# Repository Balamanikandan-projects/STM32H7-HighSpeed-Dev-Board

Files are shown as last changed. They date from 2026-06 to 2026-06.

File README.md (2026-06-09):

# STM32H7-HighSpeed-Dev-Board
An interview-ready, high-performance development platform designed around the ARM Cortex-M7 **STM32H743VIT6** microcontroller (operating at up to 480 MHz). This project showcases advanced hardware engineering principles, including 4-layer PCB stackup optimization, high-speed digital signal integrity, and isolated power management switching nodes.

## 🚀 Key Features & Specifications
* **Core Processor:** STM32H743VIT6 (ARM Cortex-M7, 480 MHz, 100-pin LQFP package).
* **Power Management:** On-board **TLV62569** high-efficiency synchronous DC-DC buck regulator stepping down 5V USB power to a stable 3.3V system rail.
* **Storage Interface:** MicroSD Card slot supporting high-bandwidth SDMMC communication profiles.
* **Connectivity:** Integrated USB-C interface protected by a **USBLC6-2SC6** low-capacitance ESD protection array.
* **Clock Systems:** Dual external oscillators—a high-speed 25 MHz system clock and a low-speed 32.768 kHz RTC clock with optimized parallel trace routing.

---

## 🛠️ Hardware Architecture & Schematic Layout

The schematic is organized into strict, modular functional blocks to ensure clean system readability:
1. **Power Supply & Input:** Raw 5V input via USB-C routed directly through ESD clamping protection into the synchronous buck regulator loop.
2. **Core Processor:** Centralized STM32H7 MCU hub surrounded closely by dedicated decoupling capacitor networks.
3. **Peripheral Storage:** High-speed data links mapped to the MicroSD interface.








---

## 🏎️ PCB Design & Signal Integrity (SI) Strategy

Designing for a 480 MHz processor requires moving beyond standard 2-layer routing limitations. This board utilizes a professional **4-layer stackup** optimized for electromagnetic compatibility (EMC):

### 🥞 4-Layer Stackup Assignment
* **Layer 1 (Top):** Component placement and high-speed signal routing.
* **Layer 2 (Inner 1):** Solid, unbroken **GND Reference Plane**.
* **Layer 3 (Inner 2):** Power Plane split into 5V and 3.3V distribution zones.
* **Layer 4 (Bottom):** Slower control lines and trace cleanup.

### 📐 Engineering Layout Constraints Implemented
* **Minimized Return Path Loops:** Every single ground pad drops directly into the Layer 2 GND plane using an adjacent via, dropping loop inductance to near-zero and eliminating ground bounce.
* **High-Speed Clock Routing:** The 25 MHz oscillator lines are short, perfectly symmetric, and run completely parallel to eliminate phase jitter.
* **EMI Suppression:** The switching node of the TLV62569 buck regulator (including input/output caps and the 1.5µH inductor) is laid out in a tight, isolated geometric loop to compress high-frequency switching noise away from analog rails.




---

## 📦 Manufacturing & Assembly Ready

The project contains a complete, automated manufacturing release package generated directly from KiCad:
* **Gerber Blueprints:** Complete 4-layer physical production layers.
* **Excellon Drill Files:** Accurate CNC hole dimensions for vias and mounting pins.
* **Bill of Materials (BOM):** Fully specified manufacturing part numbers.
* **Component Placement Files (CPL):** Pick-and-place centroid data ($X,Y$ coordinates and rotation angles) for automated assembly.

### 🔍 3D Board Visualization




---

## 📂 How to Open This Project
1. Clone this repository.
2. Download and install **KiCad v7 or later**.
3. Open the `.kicad_pro` project file to explore the fully cleared DRC schema and layout!

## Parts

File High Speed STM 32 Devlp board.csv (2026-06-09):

Id | Designator | Footprint | Quantity | Designation | Supplier and ref
1 | C_out_2,C_out_1 | C_0603_1608Metric | 2 | 22uF
2 | C11,C12,C6,C10,C7,C13,C9,C5 | C_0603_1608Metric | 8 | 100nF
3 | SW1 | SW_MEC_5GSH9 | 1 | SW_MEC_5G
4 | C3,C4 | C_0603_1608Metric | 2 | 10pF
5 | Y1 | Crystal_SMD_3215-2Pin_3.2x1.5mm | 1 | 32.768kHz
6 | C17,C16 | C_0603_1608Metric | 2 | 2.2uF
7 | 25MHz1 | Crystal_SMD_3225-4Pin_3.2x2.5mm | 1 | Crystal_GND23
8 | FB1 | R_0603_1608Metric | 1 | FerriteBead
9 | R_Damp1 | R_0603_1608Metric | 1 | 22ohm
10 | C18 | C_0603_1608Metric | 1 | 10nF
11 | J2 | PinHeader_1x05_P2.54mm_Vertical | 1 | Conn_01x05_Pin
12 | C2,C1 | C_0603_1608Metric | 2 | 12pF
13 | R2,R1 | R_0603_1608Metric | 2 | 5.1K
14 | L1 | L_Wuerth_MAPI-3012 | 1 | 1.5uH
15 | C_in1,C8 | C_0603_1608Metric | 2 | 10uF
16 | U1 | SOT-23-6 | 1 | USBLC6-2SC6
17 | C15 | C_0603_1608Metric | 1 | 4.7uf
18 | U2 | SOT-23-5 | 1 | TLV62569DBVR
19 | J3 | microSD_HC_Molex_47219-2001 | 1 | Micro_SD_Card
20 | R3 | R_0603_1608Metric | 1 | 10K
21 | C14 | C_0603_1608Metric | 1 | 4.7uF
22 | U3 | LQFP-100-1EP_14x14mm_P0.5mm_EP6.9x6.9mm | 1 | STM32H743VIT6TR
23 | J1 | USB_C_Receptacle_GCT_USB4085 | 1 | USB_C_Receptacle_USB2.0_16P

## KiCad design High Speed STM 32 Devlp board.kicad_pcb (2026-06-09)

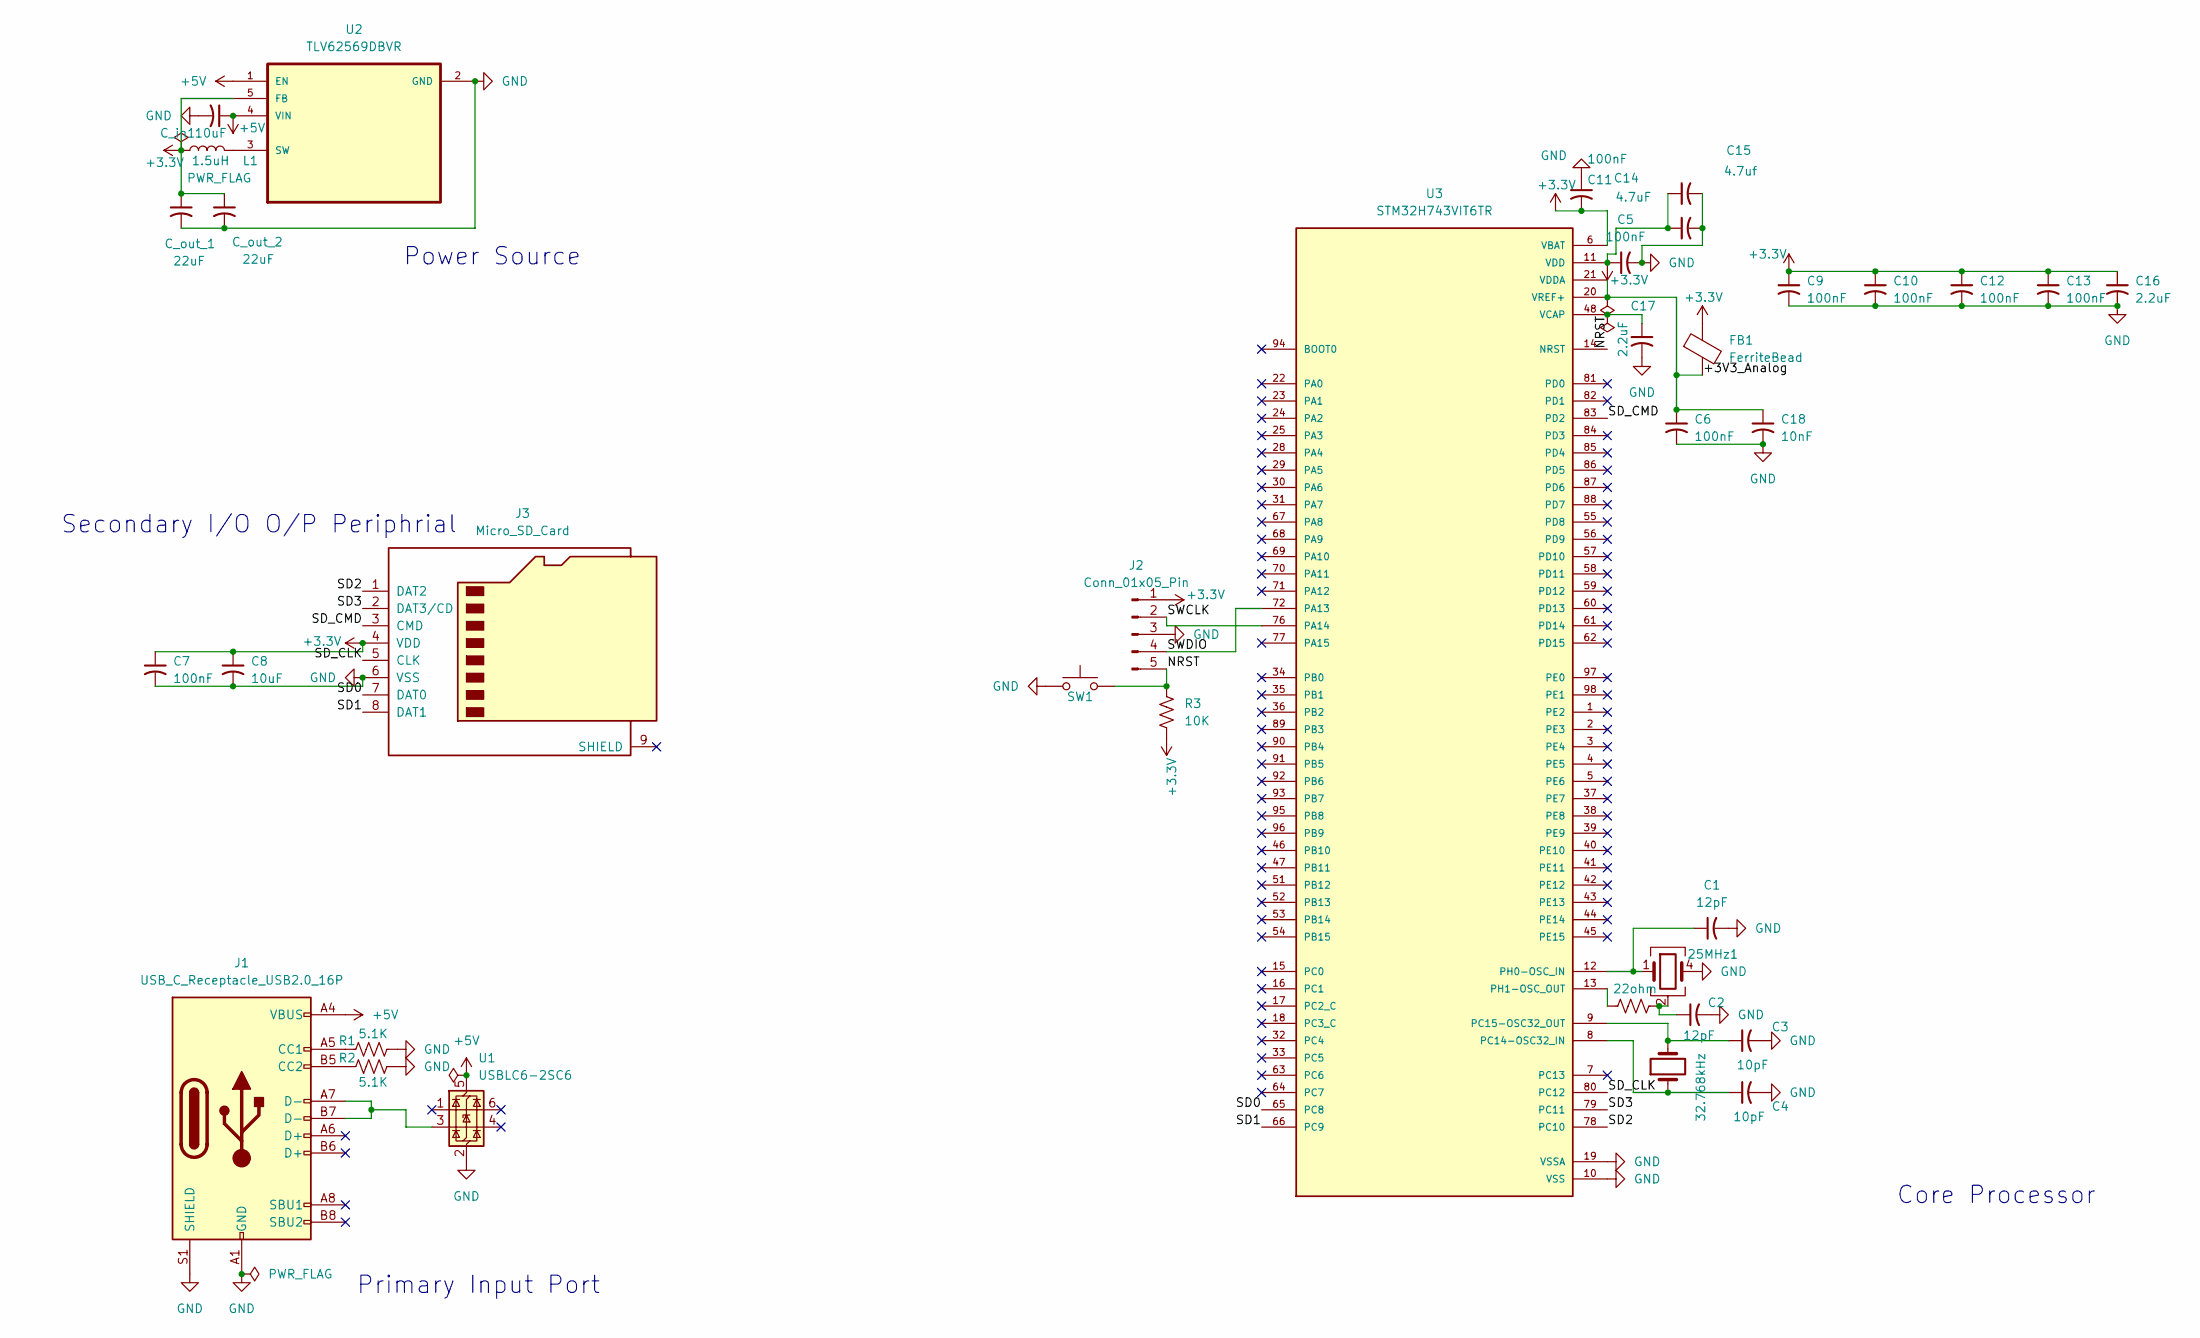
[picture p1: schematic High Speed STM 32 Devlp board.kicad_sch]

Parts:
25MHz1: Crystal_GND23; Crystal_SMD_3225-4Pin_3.2x2.5mm
C1, C2: 12pF; C_0603_1608Metric
C3, C4: 10pF; C_0603_1608Metric
C5, C6, C7, C9, C10, C11, C12, C13: 100nF; C_0603_1608Metric
C8: 10uF; C_0603_1608Metric
C14: 4.7uF; C_0603_1608Metric
C15: 4.7uf; C_0603_1608Metric
C16, C17: 2.2uF; C_0603_1608Metric
C18: 10nF; C_0603_1608Metric
C_in1: 10uF; C_0603_1608Metric
C_out_1, C_out_2: 22uF; C_0603_1608Metric
FB1: FerriteBead; R_0603_1608Metric
J1: USB_C_Receptacle_USB2.0_16P; USB_C_Receptacle_GCT_USB4085
J2: Conn_01x05_Pin; PinHeader_1x05_P2.54mm_Vertical
J3: Micro_SD_Card; microSD_HC_Molex_47219-2001
L1: 1.5uH; L_Wuerth_MAPI-3012
R1, R2: 5.1K; R_0603_1608Metric
R3: 10K; R_0603_1608Metric
R_Damp1: 22ohm; R_0603_1608Metric
SW1: SW_MEC_5G; SW_MEC_5GSH9
U1: USBLC6-2SC6; SOT-23-6
U2: TLV62569DBVR; SOT-23-5; DigiKey_Part_Number 296-47360-1-ND
U3: STM32H743VIT6TR; LQFP-100-1EP_14x14mm_P0.5mm_EP6.9x6.9mm; PARTREV 7; DigiKey_Part_Number 497-STM32H743VIT6TRCT-ND
Y1: 32.768kHz; Crystal_SMD_3215-2Pin_3.2x1.5mm

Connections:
+3.3V: C5.1, C7.1, C8.1, C9.1, C10.1, C11.2, C12.1, C13.1, C14.1, C15.1, C16.1, C_out_1.1, C_out_2.1, FB1.1, J2.1, J3.4 (VDD), L1.1, R3.1, U2.5 (FB), U3.6 (VBAT), U3.11 (VDD), U3.27 (VDD), U3.50 (VDD), U3.75 (VDD), U3.100 (VDD)
+5V: C_in1.1, J1.A4 (VBUS), J1.A9 (VBUS), J1.B4 (VBUS), J1.B9 (VBUS), U1.5 (VBUS), U2.1 (EN), U2.4 (VIN)
/+3V3_Analog: C6.1, C18.1, FB1.2, U3.20 (VREF+), U3.21 (VDDA)
/NRST: J2.5, R3.2, SW1.3 (B), SW1.4 (B), U3.14 (NRST)
/SD0: J3.7 (DAT0), U3.65 (PC8)
/SD1: J3.8 (DAT1), U3.66 (PC9)
/SD2: J3.1 (DAT2), U3.78 (PC10)
/SD3: J3.2 (DAT3/CD), U3.79 (PC11)
/SD_CLK: J3.5 (CLK), U3.80 (PC12)
/SD_CMD: J3.3 (CMD), U3.83 (PD2)
/SWCLK: J2.2, U3.76 (PA14)
/SWDIO: J2.4, U3.72 (PA13)
GND: 25MHz1.4, C1.2, C2.2, C3.2, C4.2, C5.2, C6.2, C7.2, C8.2, C9.2, C10.2, C11.1, C12.2, C13.2, C14.2, C15.2, C16.2, C17.2, C18.2, C_in1.2, C_out_1.2, C_out_2.2, J1.A1 (GND), J1.A12 (GND), J1.B1 (GND), J1.B12 (GND), J1.S1 (SHIELD), J2.3, J3.6 (VSS), R1.2, R2.2, SW1.1 (A), SW1.2 (A), U1.2 (GND), U2.2 (GND), U3.10 (VSS), U3.19 (VSSA), U3.26 (VSS), U3.49 (VSS), U3.74 (VSS), U3.99 (VSS)
unnamed: 25MHz1.2 (G), 25MHz1.3 (G), C2.1, R_Damp1.2
unnamed: J1.A5 (CC1), R1.1
unnamed: J1.B5 (CC2), R2.1
unnamed: J1.A7 (D-), J1.B7 (D-), U1.3 (I/O2)
unnamed: L1.2, U2.3 (SW)
unnamed: C4.1, U3.8 (PC14-OSC32_IN), Y1.1
unnamed: C3.1, U3.9 (PC15-OSC32_OUT), Y1.2
unnamed: 25MHz1.1, C1.1, U3.12 (PH0-OSC_IN)
unnamed: R_Damp1.1, U3.13 (PH1-OSC_OUT)
VCAP: C17.1, U3.48 (VCAP), U3.73 (VCAP)

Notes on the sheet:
Secondary I/O O/P Periphrial
Primary Input Port
Core Processor
Power Source

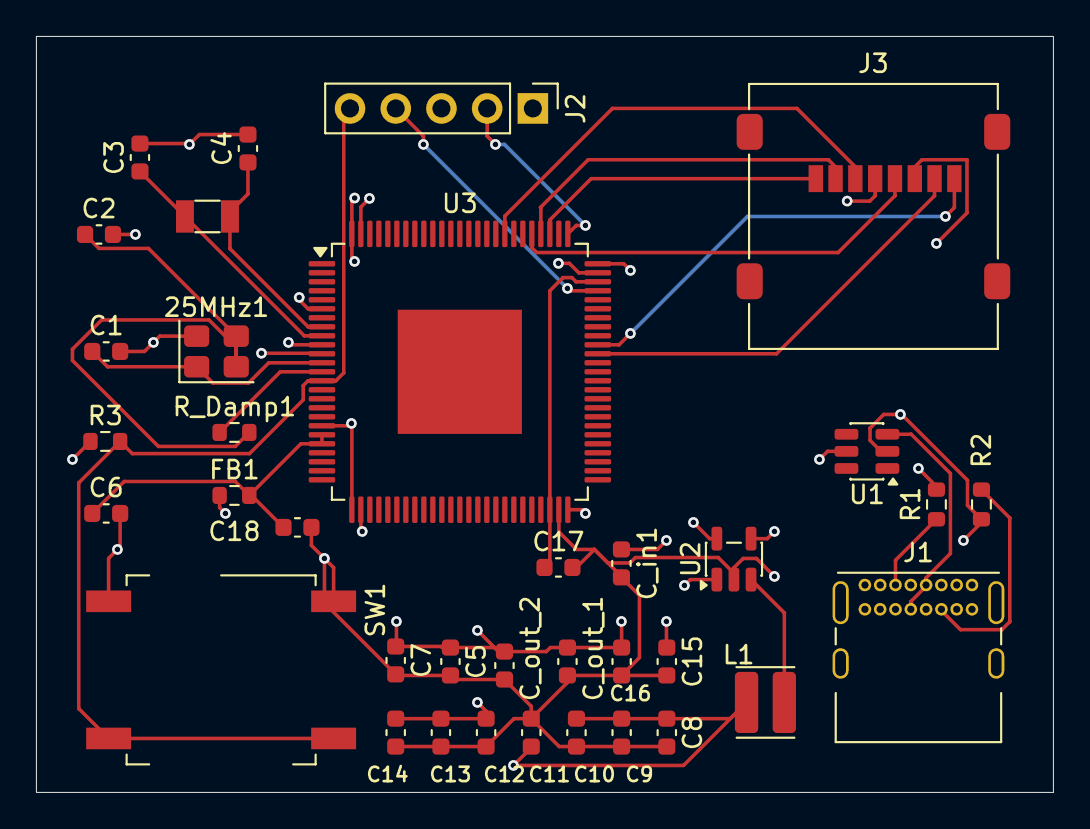
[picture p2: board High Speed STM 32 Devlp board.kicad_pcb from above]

Board: 4 copper layers, 56.5 x 42.0 mm, 36 parts (0 on the bottom side), 23 nets.
